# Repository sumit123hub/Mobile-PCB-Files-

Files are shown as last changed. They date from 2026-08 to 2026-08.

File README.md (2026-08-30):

# Custom ESP32 Mobile System PCB

I always dreamed of building my own mobile system. This repo documents my custom ESP32 PCB design featuring a GSM module, display interface, and a complete Battery Management System (BMS).

All subsystems were designed in KiCad and independently validated. Schematics, layout, and testing are complete—I'm just sourcing a suitable display for final integration.

---

## 📷 PCB Images

| Front | Back | 
| :---: | :---: |
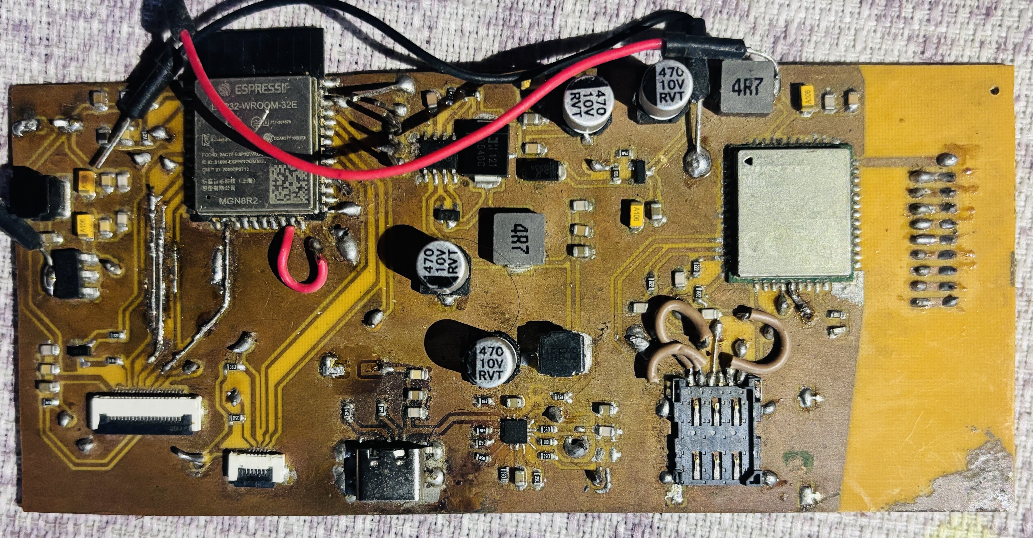
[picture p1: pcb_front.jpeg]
Front
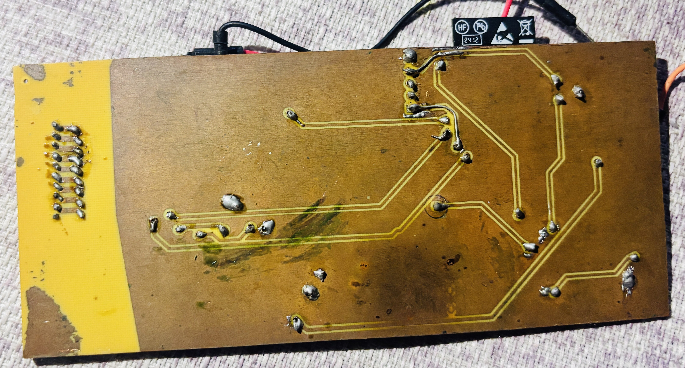
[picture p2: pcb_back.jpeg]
Back
|  |  | 

---

| KiCad View |
| :---: |
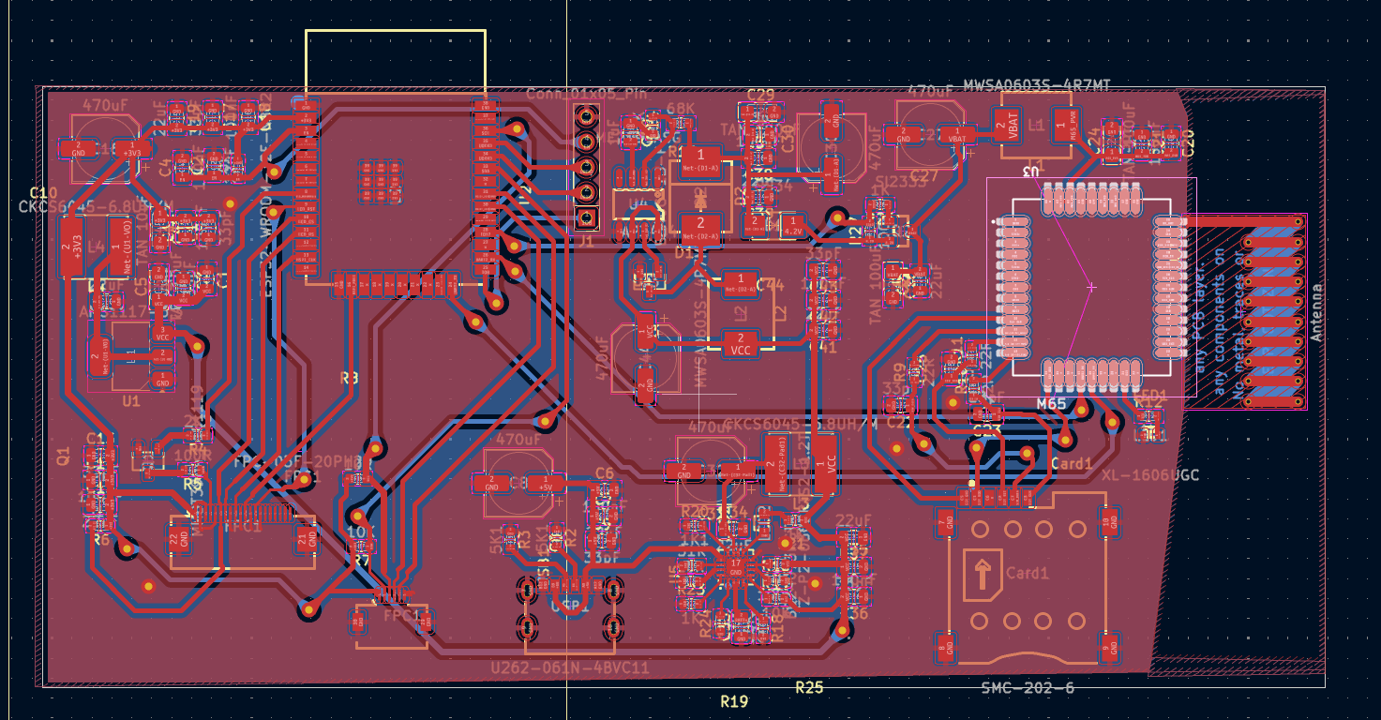
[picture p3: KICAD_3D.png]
3D View
|  |

---

## ✨ What's on the Board

| Component | Description |
| :--- | :--- |
| **ESP32-WROOM** | Main microcontroller (WiFi + BLE) |
| **GSM Module** | Quectel M65 module |
| **Charging Circuit** | BQ Chip |
| **Display Interface** | SPI for display and I2C for charhing |

---

## 📂 Files

- `Mobile_System.kicad_sch` – Schematic
- `Mobile_System.kicad_pcb` – PCB layout
- `gerbers/` – Manufacturing files
- `BOM.csv` – Bill of Materials

---

## 📌 Status

- ✅ Schematic – Complete
- ✅ PCB Layout – Complete
- ✅ BMS Validation – Passed
- ✅ GSM Validation – Passed
- ⏳ Display Integration – In progress (sourcing)
- ⏳ Firmware – Next step

---

## 🛠️ Tools

- **KiCad** – PCB design
- **Arduino / PlatformIO** – Firmware (coming soon)

---

## 👤 Author

**Sumit Sigdel**  
GitHub: [sumit123hub](https://github.com/sumit123hub)

---

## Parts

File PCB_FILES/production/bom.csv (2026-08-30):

Designator | Footprint | Quantity | Value | LCSC Part #
AE1 | Texas_SWRA416_868MHz_915MHz | 1 | Antenna
C1, C11, C13, C17, C21, C22, C23, C25, C31, C35, C43, C9 | 0805 | 12 | 33pF | C696910
C10, C15, C19, C28, C33, C34, C37, C39, C41, C7 | 0805 | 10 | 22uF | C5674
C12, C14, C18, C20, C3, C36, C38, C42, C6 | 0805 | 9 | 100nF | C392963
C16, C27, C30, C32, C44, C8 | CP_Elec_6.3x7.7 | 6 | 470uF | C5189822
C2 | 0805 | 1 | 22uF
C24, C26, C29 | CP_EIA-3216-18_Kemet-A | 3 | TAN 100uF | C27279
C4 | 0805 | 1 | 100nF
C40 | 0805 | 1 | 1uF | C28323
C45, C5 | CP_EIA-3216-18_Kemet-A | 2 | TAN 10uF | C27279
CARD1 | SIM-SMD_SMC-202-6 | 1 | SMC-202-6 | C266634
D1 | DO-214AC_L4.3-W2.7-LS5.0-RD | 1 | SS34 | C2836396
D2 | SMC_L7.1-W6.2-LS8.1-RD | 1 | B540C-13-F | C72264
FPC1 | touch_display_3.5inch | 1 | FPC-05F-20PH20
J1 | PinHeader_1x05_P2.54mm_Vertical | 1 | Conn_01x05_Pin
L1, L2 | IND-SMD_L7.0-W6.6 | 2 | MWSA0603S-4R7MT | C2937097
L3, L4 | IND-SMD_L6.0-W6.0 | 2 | CKCS6045-6.8UH/M | C57254
LED1 | LED-SMD_L1.7-W1.1-R-RD_GREEN | 1 | XL-1606UGC | C965863
LED2 | LED-SMD_L1.6-W1.2-RD | 1 | TZ-P2-0602RTS2-1.2T | C688879
Q1 | SOT-23-3_L2.9-W1.6-P1.90-LS2.8-BR | 1 | MMBT3904_C181119 | C181119
Q2 | SOT-23_L2.9-W1.3-P1.90-LS2.4-BR | 1 | SI2333 | C4748717
Q3 | SOT-23-3_L2.9-W1.3-P1.90-LS2.4-BR-2 | 1 | AP3404 | C2842665
R1 | 0603 | 1 | 10k
R10, R11, R9 | 0603 | 3 | 22R | C3016215
R12 | 0603 | 1 | 1K | C2907179
R13 | 0603 | 1 | 68K | C2907196
R14 | 0603 | 1 | 27K | C22967
R16, R27 | 0603 | 2 | 100K | C25803
R17, R18, R21, R24, R25, R7, R8 | 0603 | 7 | 10K | C3017715
R19, R6 | 0603 | 2 | 51K | C2907180
R2, R3 | 0603 | 2 | 5K1 | C2907114
R20 | 0603 | 1 | 1K1 | C2906975
R22 | 0603 | 1 | 1K | C103309
R23, R26 | 0603 | 2 | 1K | C3017736
R4 | 0603 | 1 | 2K2 | C2907117
R5 | 0603 | 1 | 100R | C125923
U1 | SOT-223-3_TabPin2 | 1 | AMS1117-3.3
U2 | WIFI-SMD_ESP32-WROOM-32E | 1 | ESP32-WROOM-32E-N8R2 | C5361945
U3 | XCVR_M65 | 1 | M65 | Y100443
U4 | SOP-8_L4.9-W3.9-P1.27-LS6.0-BL | 1 | ME2199ASG | C2875120
U5 | QFN-16_L3.0-W3.0-P0.50-TL-EP1.7 | 1 | BQ24073RGTR | C15220
USB1 | USB-SMD_U262-061N-4BVC11 | 1 | U262-061N-4BVC11 | C2764612

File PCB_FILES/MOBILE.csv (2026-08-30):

Id | Designator | Footprint | Quantity | Designation | Supplier and ref
1 | R2,R3 | R_0603_1608Metric | 2 | 5K1
2 | C25,C1,C9,C17,C11,C43,C31,C21,C13,C35,C23,C22 | C_0805_2012Metric | 12 | 33pF
3 | Card1 | SIM-SMD_SMC-202-6 | 1 | SMC-202-6
4 | R4 | R_0603_1608Metric | 1 | 2K2
5 | C3,C18,C12,C4,C38,C42,C20,C14,C36,C6 | C_0805_2012Metric | 10 | 100nF
6 | Q2 | SOT-23_L2.9-W1.3-P1.90-LS2.4-BR | 1 | SI2333
7 | U1 | SOT-223-3_TabPin2 | 1 | AMS1117-3.3
8 | C19,C41,C28,C2,C34,C33,C39,C37,C7,C10,C15 | C_0805_2012Metric | 11 | 22uF
9 | L3,L4 | IND-SMD_L6.0-W6.0 | 2 | CKCS6045-6.8UH/M
10 | R1 | R_0603_1608Metric | 1 | 10k
11 | R11,R10,R9 | R_0603_1608Metric | 3 | 22R
12 | R8,R25,R17,R21,R24,R18,R7 | R_0603_1608Metric | 7 | 10K
13 | C27,C8,C16,C32,C44,C30 | CP_Elec_6.3x7.7 | 6 | 470uF
14 | R19,R6 | R_0603_1608Metric | 2 | 51K
15 | Q3 | SOT-23-3_L2.9-W1.3-P1.90-LS2.4-BR-2 | 1 | AP3404
16 | AE1 | Texas_SWRA416_868MHz_915MHz | 1 | Antenna
17 | U3 | XCVR_M65 | 1 | M65
18 | C45,C5 | CP_EIA-3216-18_Kemet-A | 2 | TAN 10uF
19 | R22,R12,R26,R23 | R_0603_1608Metric | 4 | 1K
20 | R5 | R_0603_1608Metric | 1 | 100R
21 | R13 | R_0603_1608Metric | 1 | 68K
22 | J1 | PinHeader_1x05_P2.54mm_Vertical | 1 | Conn_01x05_Pin
23 | R20 | R_0603_1608Metric | 1 | 1K1
24 | LED2 | LED-SMD_L1.6-W1.2-RD | 1 | TZ-P2-0602RTS2-1.2T
25 | L1,L2 | IND-SMD_L7.0-W6.6 | 2 | MWSA0603S-4R7MT
26 | U4 | SOP-8_L4.9-W3.9-P1.27-LS6.0-BL | 1 | ME2199ASG
27 | USB1 | USB-SMD_U262-061N-4BVC11 | 1 | U262-061N-4BVC11
28 | Q1 | SOT-23-3_L2.9-W1.6-P1.90-LS2.8-BR | 1 | MMBT3904_C181119
29 | D2 | SMC_L7.1-W6.2-LS8.1-RD | 1 | B540C-13-F
30 | C40 | C_0805_2012Metric | 1 | 1uF
31 | U5 | QFN-16_L3.0-W3.0-P0.50-TL-EP1.7 | 1 | BQ24073RGTR
32 | C24,C29,C26 | CP_EIA-3216-18_Kemet-A | 3 | TAN 100uF
33 | R14 | R_0603_1608Metric | 1 | 27K
34 | R27,R16 | R_0603_1608Metric | 2 | 100K
35 | LED1 | LED-SMD_L1.7-W1.1-R-RD_GREEN | 1 | XL-1606UGC
36 | FPC1 | touch_display_3.5inch | 1 | FPC-05F-20PH20
37 | D1 | DO-214AC_L4.3-W2.7-LS5.0-RD | 1 | SS34
38 | U2 | WIFI-SMD_ESP32-WROOM-32E | 1 | ESP32-WROOM-32E-N8R2

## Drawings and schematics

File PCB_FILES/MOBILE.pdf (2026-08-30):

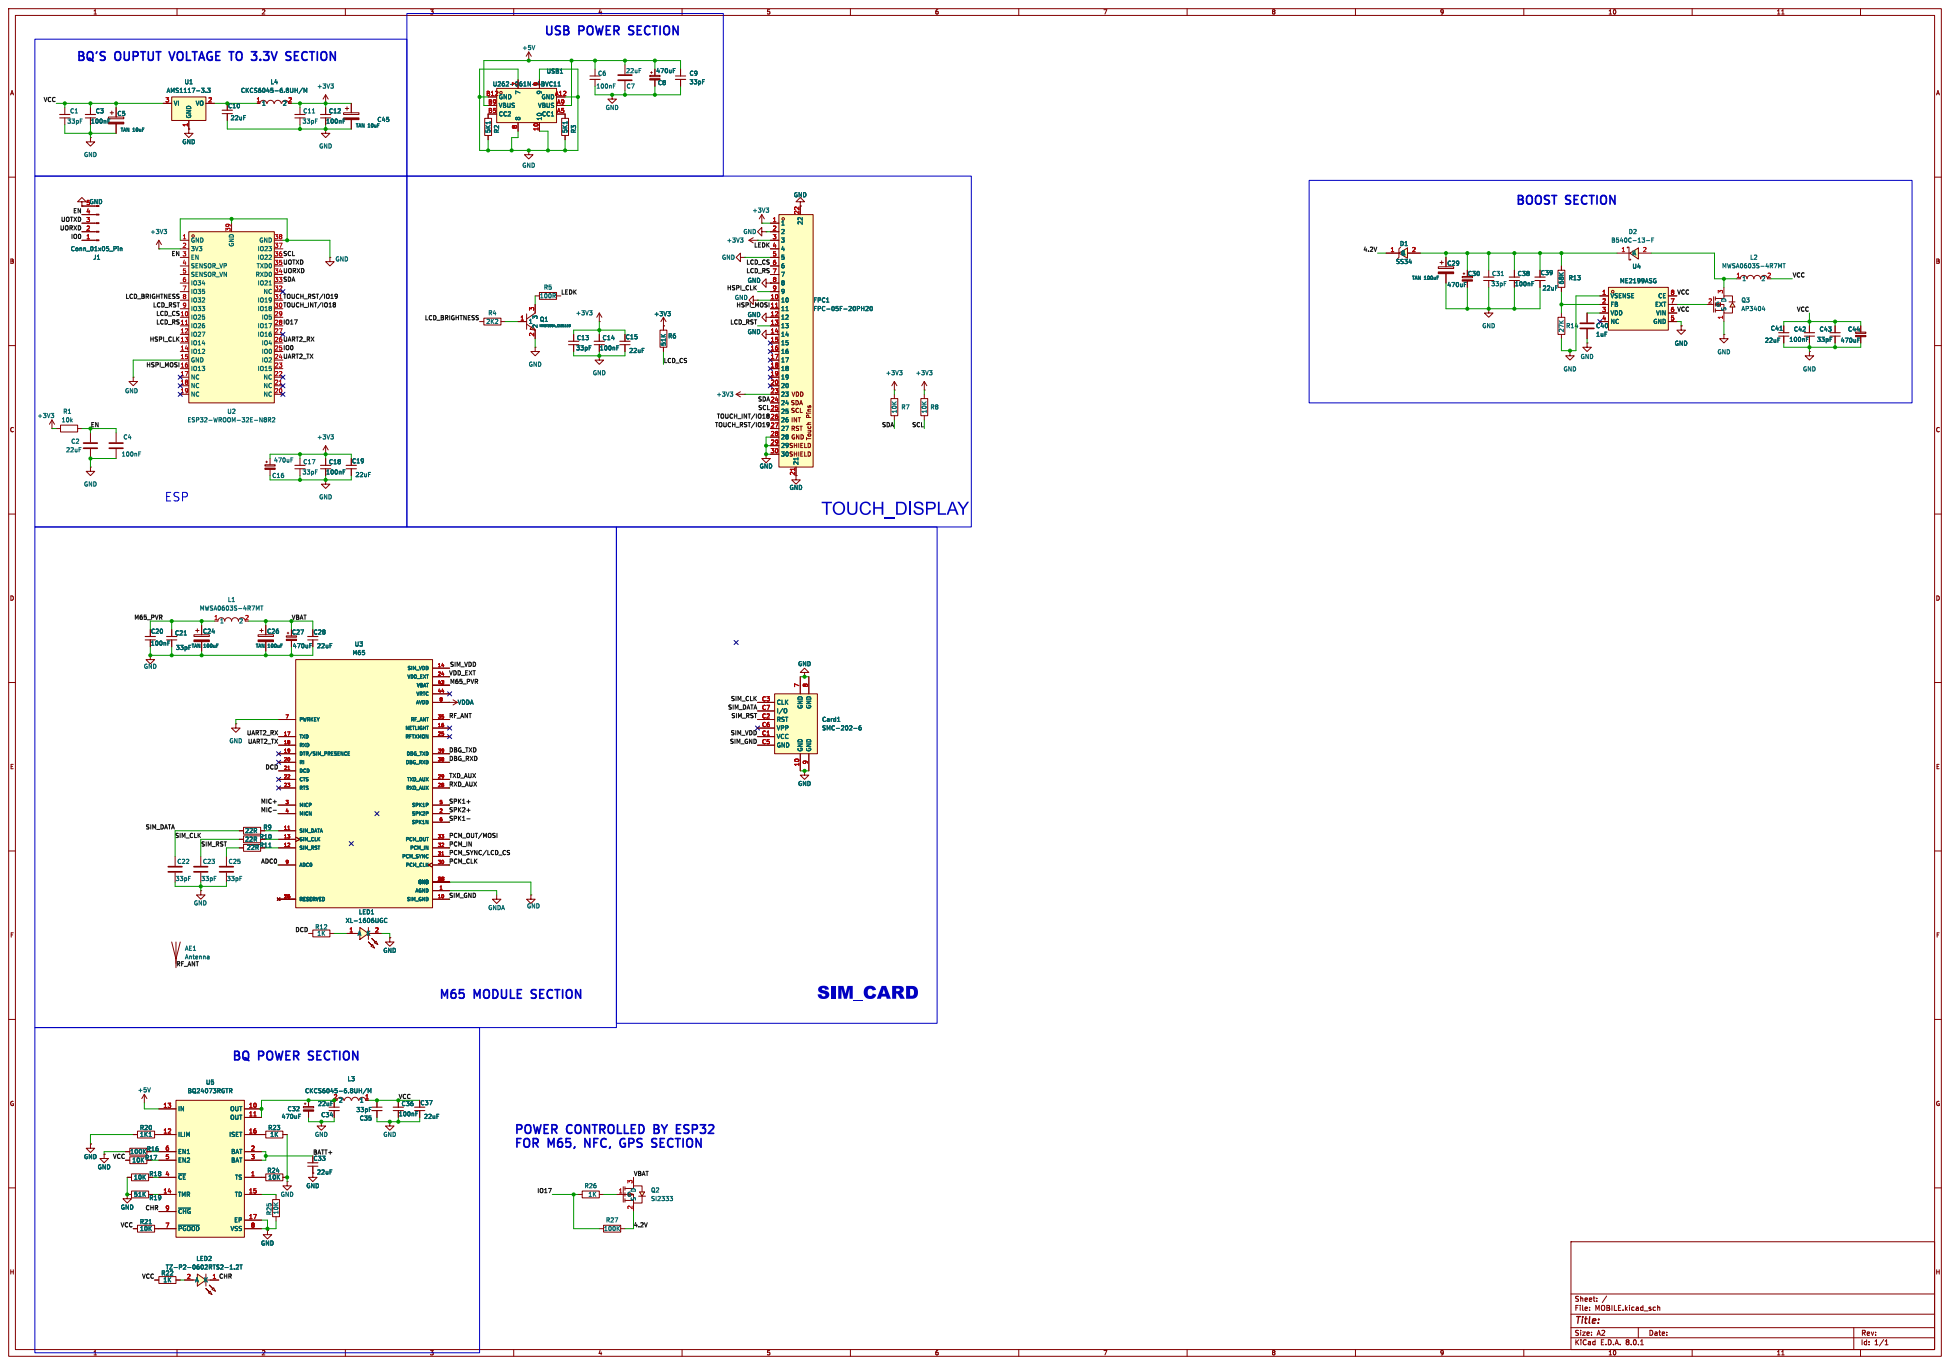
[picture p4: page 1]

BQ'S OUPTUT VOLTAGE TO 3.3V SECTION

9 VCC C1 RST C2 CLK C3 GND C5 VPP C6

POWER CONTROLLED BY ESP32
FOR M65, NFC, GPS SECTION

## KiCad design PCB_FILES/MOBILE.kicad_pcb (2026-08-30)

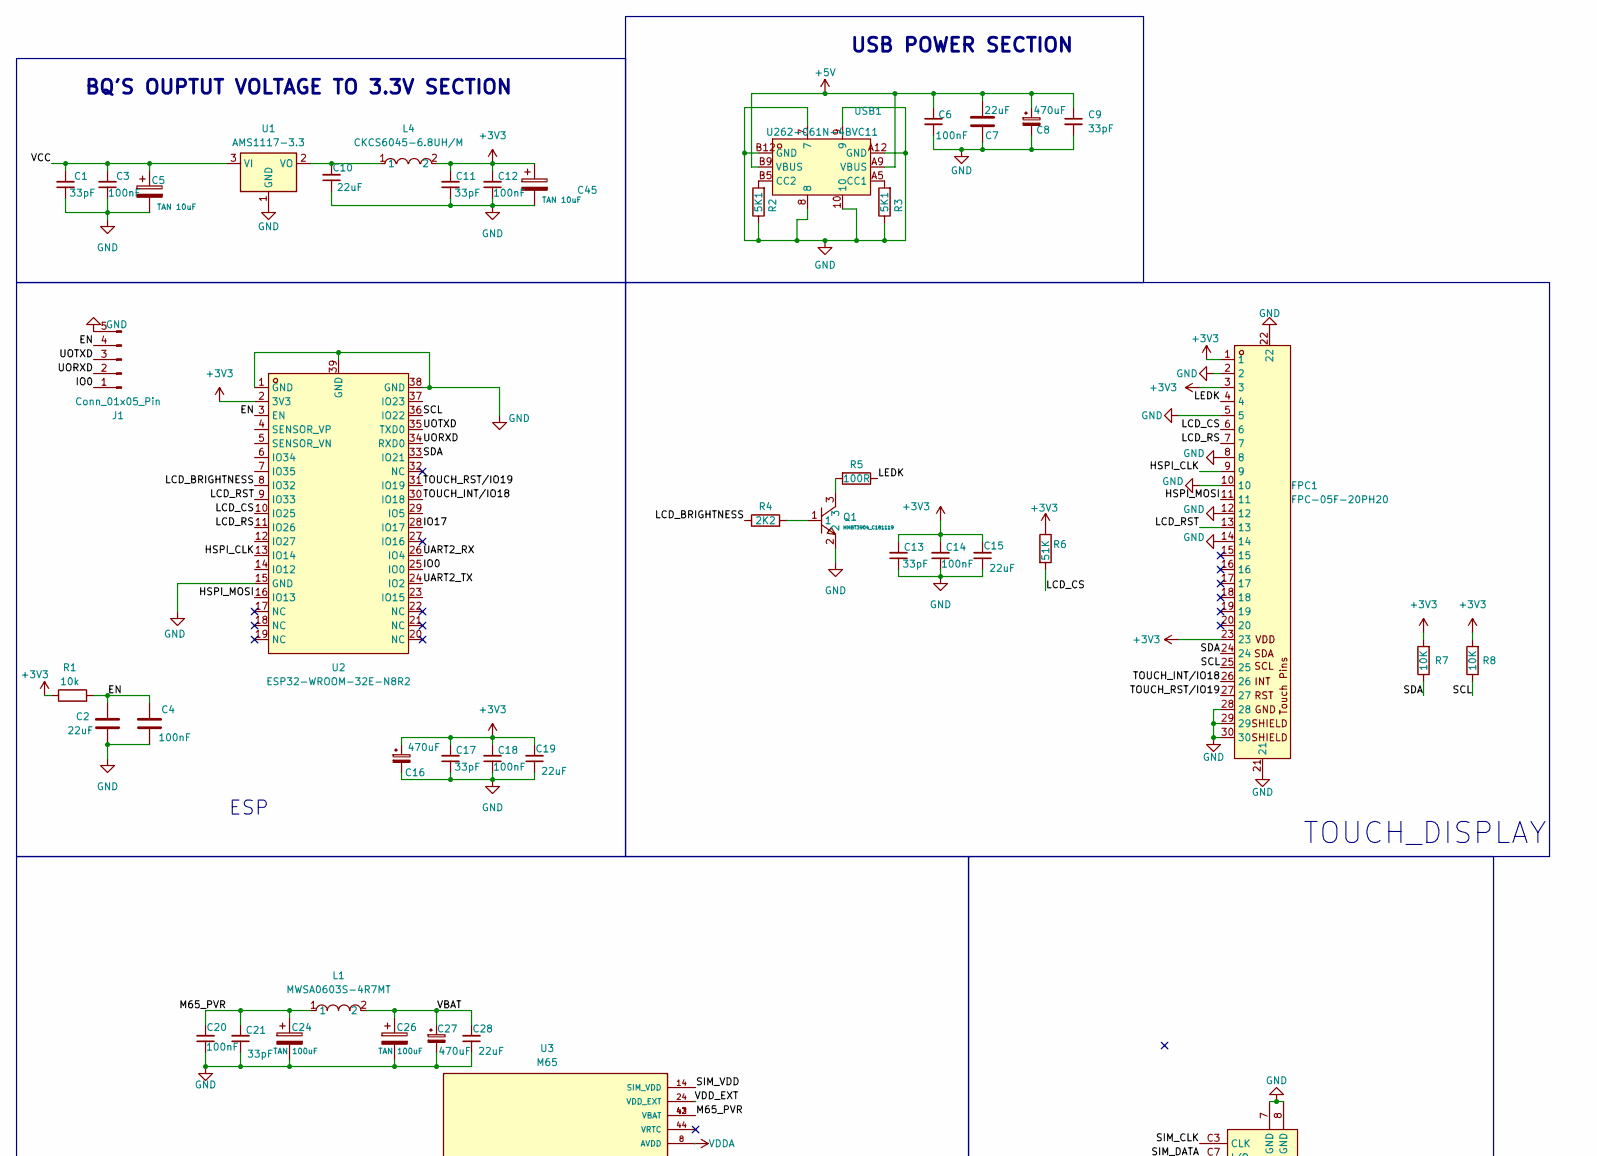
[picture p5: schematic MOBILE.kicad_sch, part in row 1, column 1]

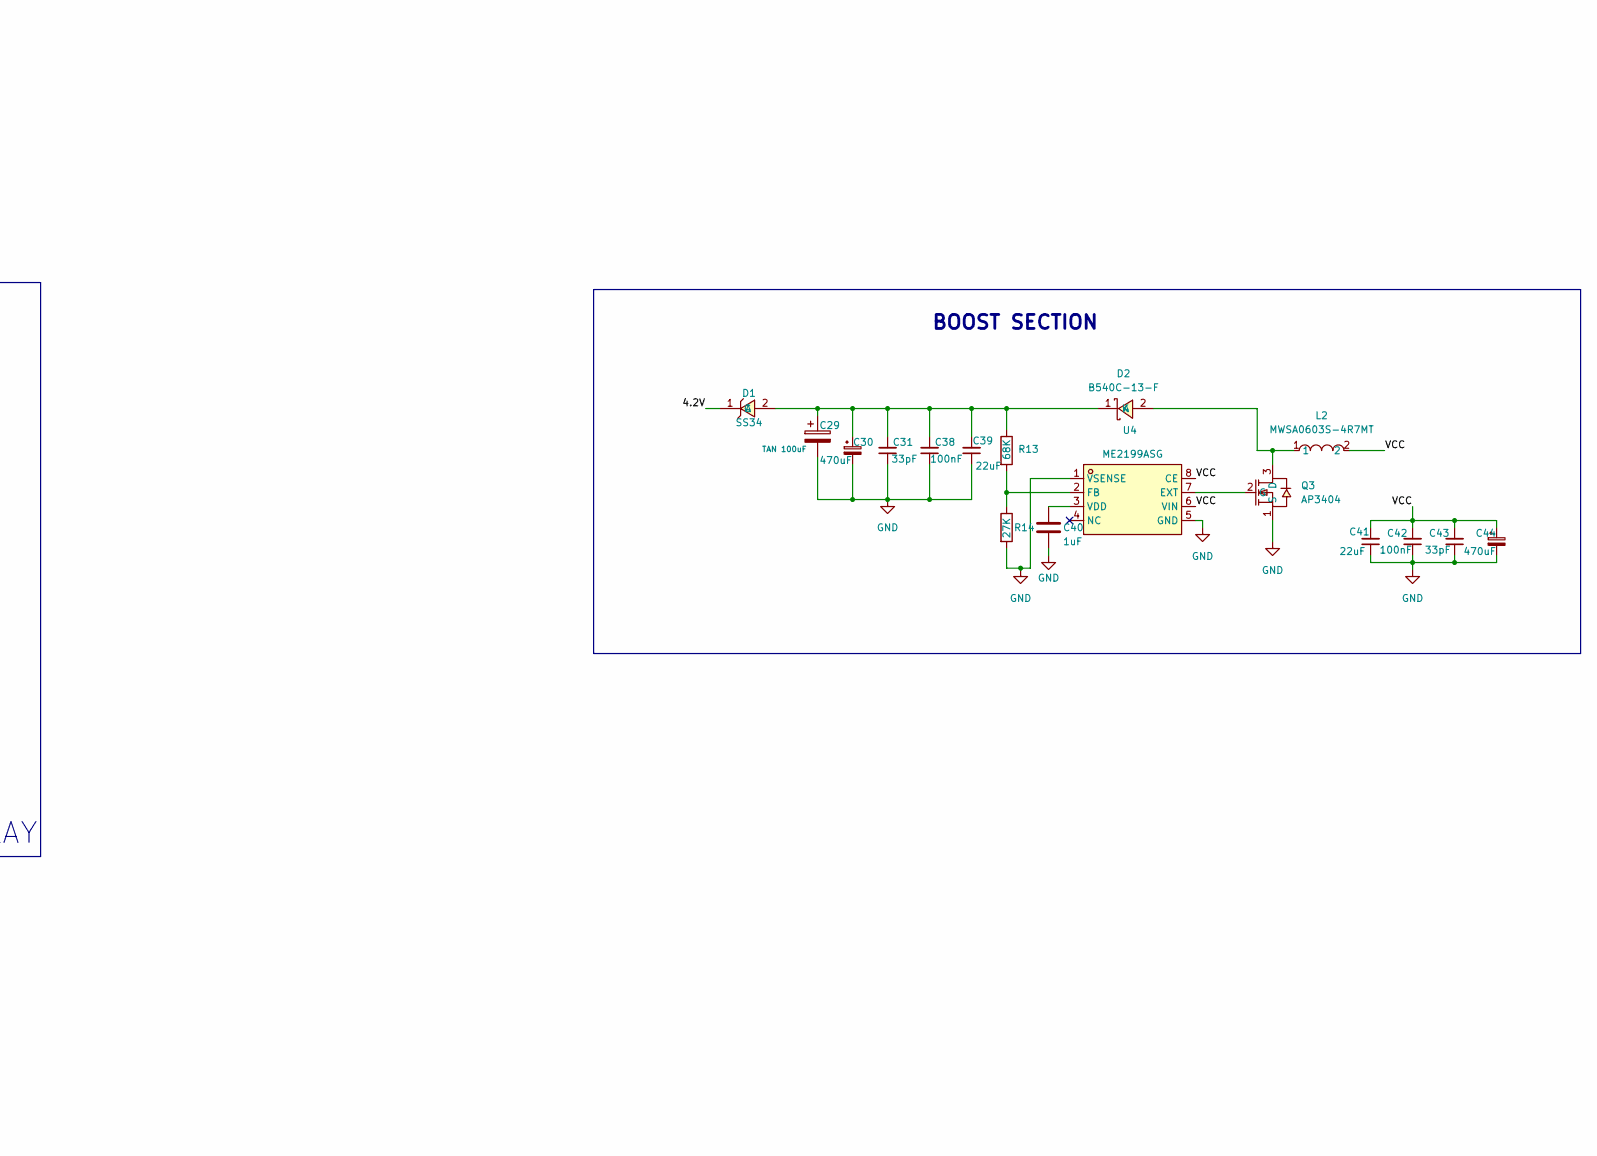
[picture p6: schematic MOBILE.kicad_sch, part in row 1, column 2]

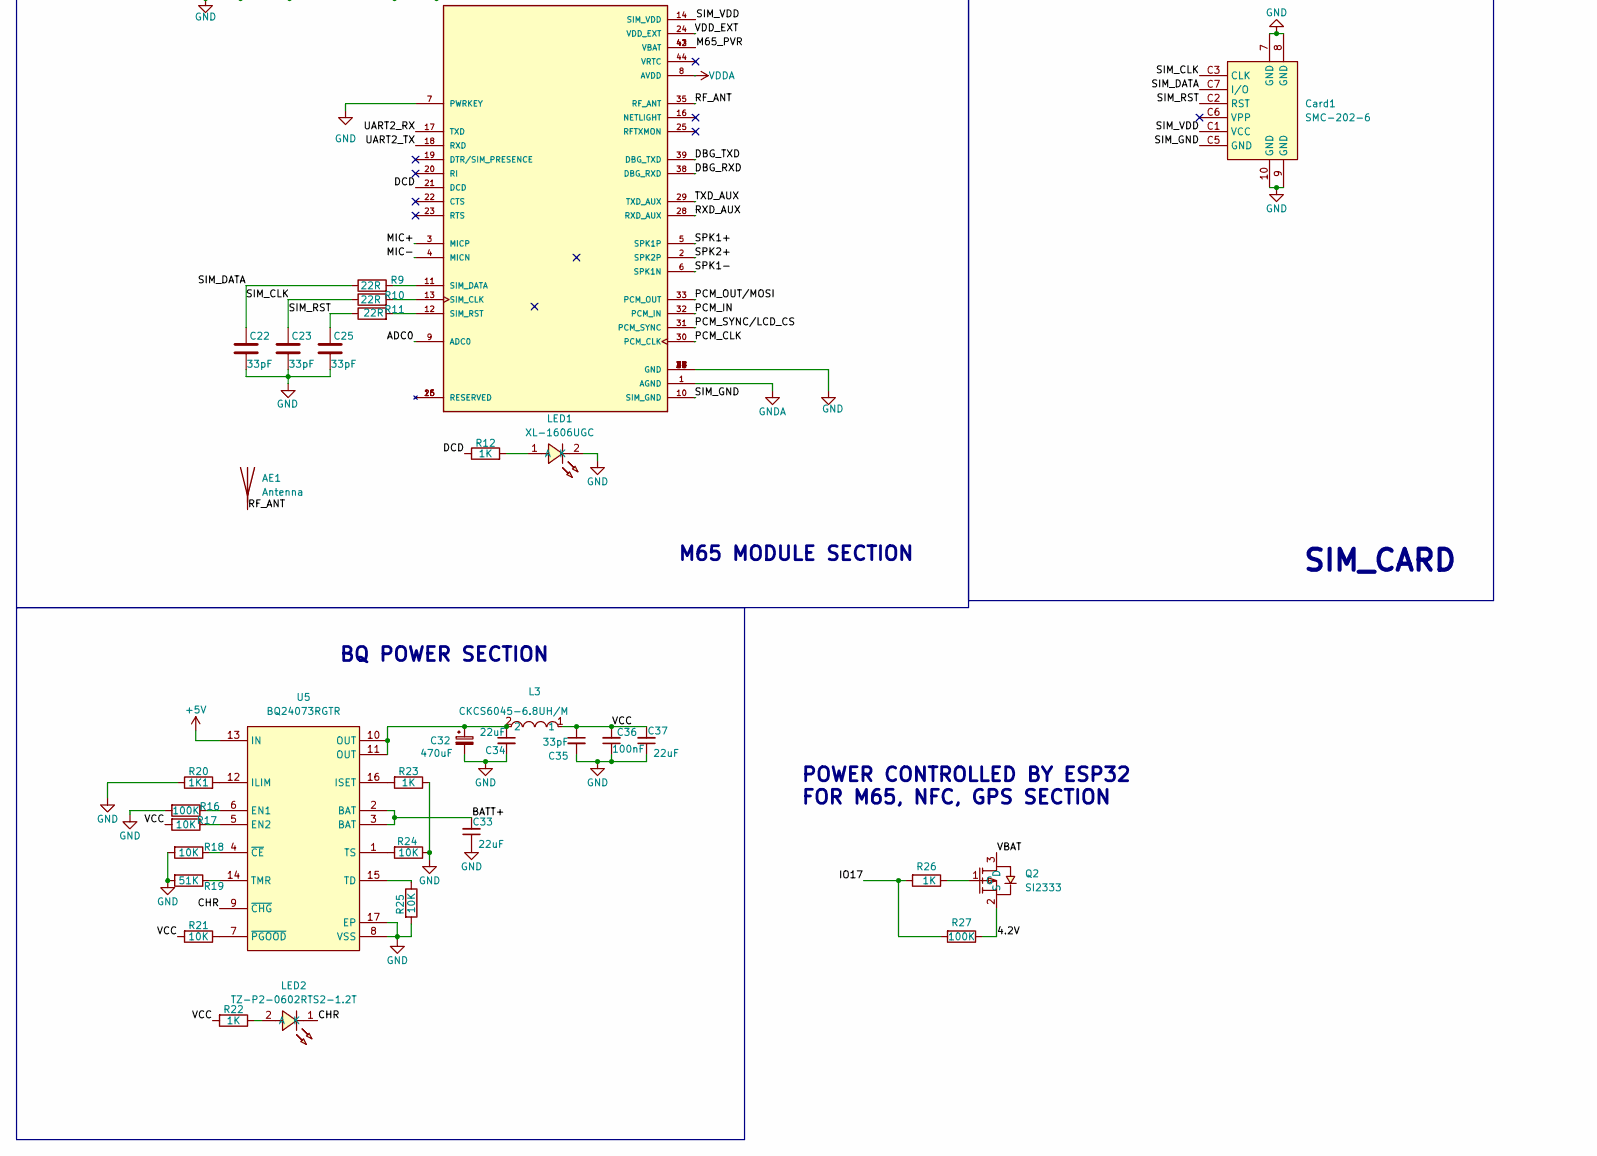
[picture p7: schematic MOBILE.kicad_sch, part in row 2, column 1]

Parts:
AE1: Antenna; Texas_SWRA416_868MHz_915MHz
C1, C11, C13, C17, C21, C31, C35, C43: 33pF; C_0805_2012Metric; LCSC Part # C696910
C2: 22uF; C_0805_2012Metric
C3, C12, C14, C18, C20, C36, C38, C42: 100nF; C_0805_2012Metric; LCSC Part # C392963
C4: 100nF; C_0805_2012Metric
C5, C45: TAN 10uF; CP_EIA-3216-18_Kemet-A; LCSC Part # C27279
C6: 100nF; C_0805_2012Metric; LCSC Part C392963
C7, C10, C15, C19, C28, C33, C34, C37, C39, C41: 22uF; C_0805_2012Metric; LCSC Part # C5674
C8, C16, C27, C30, C32, C44: 470uF; CP_Elec_6.3x7.7; LCSC Part # C5189822
C9, C22, C23, C25: 33pF; C_0805_2012Metric; LCSC Part C696910
C24, C26, C29: TAN 100uF; CP_EIA-3216-18_Kemet-A; LCSC Part # C27279
C40: 1uF; C_0805_2012Metric; LCSC Part C28323
Card1: SMC-202-6; SIM-SMD_SMC-202-6; LCSC Part C266634
D1: SS34; DO-214AC_L4.3-W2.7-LS5.0-RD; LCSC Part # C2836396
D2: B540C-13-F; SMC_L7.1-W6.2-LS8.1-RD; LCSC Part C72264
FPC1: FPC-05F-20PH20; touch_display_3.5inch; LCSC Part C2856803
J1: Conn_01x05_Pin; PinHeader_1x05_P2.54mm_Vertical
L1, L2: MWSA0603S-4R7MT; IND-SMD_L7.0-W6.6; LCSC Part C408447
L3, L4: CKCS6045-6.8UH/M; IND-SMD_L6.0-W6.0; LCSC Part C57254
LED1: XL-1606UGC; LED-SMD_L1.7-W1.1-R-RD_GREEN; LCSC Part C965863
LED2: TZ-P2-0602RTS2-1.2T; LED-SMD_L1.6-W1.2-RD; LCSC Part C688879
Q1: MMBT3904_C181119; SOT-23-3_L2.9-W1.6-P1.90-LS2.8-BR; LCSC Part C181119
Q2: SI2333; SOT-23_L2.9-W1.3-P1.90-LS2.4-BR; LCSC Part C4748717
Q3: AP3404; SOT-23-3_L2.9-W1.3-P1.90-LS2.4-BR-2; LCSC Part C2842665
R1: 10k; R_0603_1608Metric
R2, R3: 5K1; R_0603_1608Metric; LCSC Part # C2907114
R4: 2K2; R_0603_1608Metric; LCSC Part C2907117
R5: 100R; R_0603_1608Metric; LCSC Part C125923
R6: 51K; R_0603_1608Metric; LCSC Part C2907180
R7, R8, R17, R18, R21, R24, R25: 10K; R_0603_1608Metric; LCSC Part # C3017715
R9, R10, R11: 22R; R_0603_1608Metric; LCSC Part C3016215
R12: 1K; R_0603_1608Metric; LCSC Part # C2907179
R13: 68K; R_0603_1608Metric; LCSC Part C2907196
R14: 27K; R_0603_1608Metric; LCSC Part C22967
R16, R27: 100K; R_0603_1608Metric; LCSC Part # C25803
R19: 51K; R_0603_1608Metric; LCSC Part # C2907180
R20: 1K1; R_0603_1608Metric; LCSC Part # C2906975
R22: 1K; R_0603_1608Metric; LCSC Part # C103309
R23, R26: 1K; R_0603_1608Metric; LCSC Part # C3017736
U1: AMS1117-3.3; SOT-223-3_TabPin2
U2: ESP32-WROOM-32E-N8R2; WIFI-SMD_ESP32-WROOM-32E; LCSC Part C5361945
U3: M65; XCVR_M65; PARTREV 1.0; LCSC Part Y100443
U4: ME2199ASG; SOP-8_L4.9-W3.9-P1.27-LS6.0-BL; LCSC Part # C2875120
U5: BQ24073RGTR; QFN-16_L3.0-W3.0-P0.50-TL-EP1.7; LCSC Part C15220
USB1: U262-061N-4BVC11; USB-SMD_U262-061N-4BVC11; LCSC Part C2764612

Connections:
+3V3: C11.2, C12.2, C13.2, C14.2, C15.2, C16.1, C17.2, C18.2, C19.2, C45.1, FPC1.1, FPC1.3, FPC1.23, L4.2, R1.1, R6.1, R7.2, R8.2, U2.2 (3V3)
+5V: C6.1, C7.1, C8.1, C9.1, U5.13 (IN), USB1.A9 (VBUS), USB1.B9 (VBUS)
/4.2V: D1.1 (C), Q2.2 (S), R27.1
/ADC0: U3.9 (ADC0)
/BATT+: C33.2, U5.2 (BAT), U5.3 (BAT)
/CHR: LED2.1 (K), U5.9 (~CHG)
/DBG_RXD: U3.38 (DBG_RXD)
/DBG_TXD: U3.39 (DBG_TXD)
/DCD: R12.1, U3.21 (DCD)
/EN: C2.1, C4.1, J1.4, R1.2, U2.3 (EN)
/HSPI_CLK: FPC1.9, U2.13 (IO14)
/HSPI_MOSI: FPC1.11, U2.16 (IO13)
/IO0: J1.1, U2.25 (IO0)
/IO17: R26.2, R27.2, U2.28 (IO17)
/LCD_BRIGHTNESS: R4.1, U2.8 (IO32)
/LCD_CS: FPC1.6, R6.2, U2.10 (IO25)
/LCD_RS: FPC1.7, U2.11 (IO26)
/LCD_RST: FPC1.13, U2.9 (IO33)
/LEDK: FPC1.4, R5.1
/M65_PVR: C20.2, C21.2, C24.1, L1.1, U3.42 (VBAT), U3.43 (VBAT)
/MIC+: U3.3 (MICP)
/MIC-: U3.4 (MICN)
/PCM_CLK: U3.30 (PCM_CLK)
/PCM_IN: U3.32 (PCM_IN)
/PCM_OUT/MOSI: U3.33 (PCM_OUT)
/PCM_SYNC/LCD_CS: U3.31 (PCM_SYNC)
/RF_ANT: AE1.1 (A), U3.35 (RF_ANT)
/RXD_AUX: U3.28 (RXD_AUX)
/SCL: FPC1.25, R8.1, U2.36 (IO22)
/SDA: FPC1.24, R7.1, U2.33 (IO21)
/SIM_CLK: C23.1, Card1.C3 (CLK), R10.1
/SIM_DATA: C22.1, Card1.C7 (I/O), R9.1
/SIM_GND: Card1.C5 (GND), U3.10 (SIM_GND)
/SIM_RST: C25.1, Card1.C2 (RST), R11.1
/SIM_VDD: Card1.C1 (VCC), U3.14 (SIM_VDD)
/SPK1+: U3.5 (SPK1P)
/SPK1-: U3.6 (SPK1N)
/SPK2+: U3.2 (SPK2P)
/TOUCH_INT/IO18: FPC1.26, U2.30 (IO18)
/TOUCH_RST/IO19: FPC1.27, U2.31 (IO19)
/TXD_AUX: U3.29 (TXD_AUX)
/UART2_RX: U2.26 (IO4), U3.17 (TXD)
/UART2_TX: U2.24 (IO2), U3.18 (RXD)
/UORXD: J1.2, U2.34 (RXD0)
/UOTXD: J1.3, U2.35 (TXD0)
/VBAT: C26.1, C27.1, C28.2, L1.2, Q2.3 (D)
/VCC: C1.2, C3.2, C5.1, C35.1, C36.2, C37.2, C41.2, C42.2, C43.2, C44.1, L2.2, L3.1, R17.2, R21.2, R22.2, U1.3 (VI), U4.6 (VIN), U4.8 (CE)
/VDD_EXT: U3.24 (VDD_EXT)
GND: C1.1, C2.2, C3.1, C4.2, C5.2, C6.2, C7.2, C8.2, C9.2, C10.1, C11.1, C12.1, C13.1, C14.1, C15.1, C16.2, C17.1, C18.1, C19.1, C20.1, C21.1, C22.2, C23.2, C24.2, C25.2, C26.2, C27.2, C28.1, C29.2, C30.2, C31.1, C32.2, C33.1, C34.2, C35.2, C36.1, C37.1, C38.1, C39.1, C40.1, C41.1, C42.1, C43.1, C44.2, C45.2, Card1.7 (GND), Card1.8 (GND), Card1.9 (GND), Card1.10 (GND), FPC1.2, FPC1.5, FPC1.8, FPC1.10, FPC1.12, FPC1.14, FPC1.21, FPC1.22, FPC1.28, FPC1.29, FPC1.30, J1.5, LED1.2 (K), Q1.2, Q3.1 (S), R2.1, R3.1, R14.2, R16.2, R18.2, R19.2, R20.1, R23.1, R24.1, R25.2, U1.1 (GND), U2.1 (GND), U2.15 (GND), U2.38 (GND), U2.39 (GND), U3.7 (PWRKEY), U3.27 (GND), U3.34 (GND), U3.36 (GND), U3.37 (GND), U3.40 (GND), U3.41 (GND), U4.1 (VSENSE), U4.5 (GND), U5.8 (VSS), U5.17 (EP), USB1.7, USB1.8, USB1.9, USB1.10, USB1.A12 (GND), USB1.B12 (GND)
GNDA: U3.1 (AGND)
unnamed: C32.1, C34.1, L3.2, U5.10 (OUT), U5.11 (OUT)
unnamed: C29.1, C30.1, C31.2, C38.2, C39.2, D1.2 (A), D2.1 (K), R13.1
unnamed: D2.2 (A), L2.1, Q3.3 (D)
unnamed: LED1.1 (A), R12.2
unnamed: LED2.2 (A), R22.1
unnamed: Q1.1, R4.2
unnamed: Q1.3, R5.2
unnamed: Q2.1 (G), R26.1
unnamed: Q3.2 (G), U4.7 (EXT)
unnamed: C10.2, L4.1, U1.2 (VO)
unnamed: R10.2, U3.13 (SIM_CLK)
unnamed: R9.2, U3.11 (SIM_DATA)
unnamed: R11.2, U3.12 (SIM_RST)
unnamed: R13.2, R14.1, U4.2 (FB)
unnamed: C40.2, U4.3 (VDD)
unnamed: R16.1, U5.6 (EN1)
unnamed: R17.1, U5.5 (EN2)
unnamed: R20.2, U5.12 (ILIM)
unnamed: R23.2, U5.16 (ISET)
unnamed: R25.1, U5.15 (TD)
unnamed: R19.1, U5.14 (TMR)
unnamed: R24.2, U5.1 (TS)
unnamed: R18.1, U5.4 (~CE)
unnamed: R21.1, U5.7 (~PGOOD)
unnamed: R3.2, USB1.A5 (CC1)
unnamed: R2.2, USB1.B5 (CC2)
VDDA: U3.8 (AVDD)

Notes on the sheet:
USB POWER SECTION
POWER CONTROLLED BY ESP32 FOR M65, NFC, GPS SECTION
TOUCH_DISPLAY
ESP
SIM_CARD
M65 MODULE SECTION
BOOST SECTION
BQ'S OUPTUT VOLTAGE TO 3.3V SECTION
BQ POWER SECTION

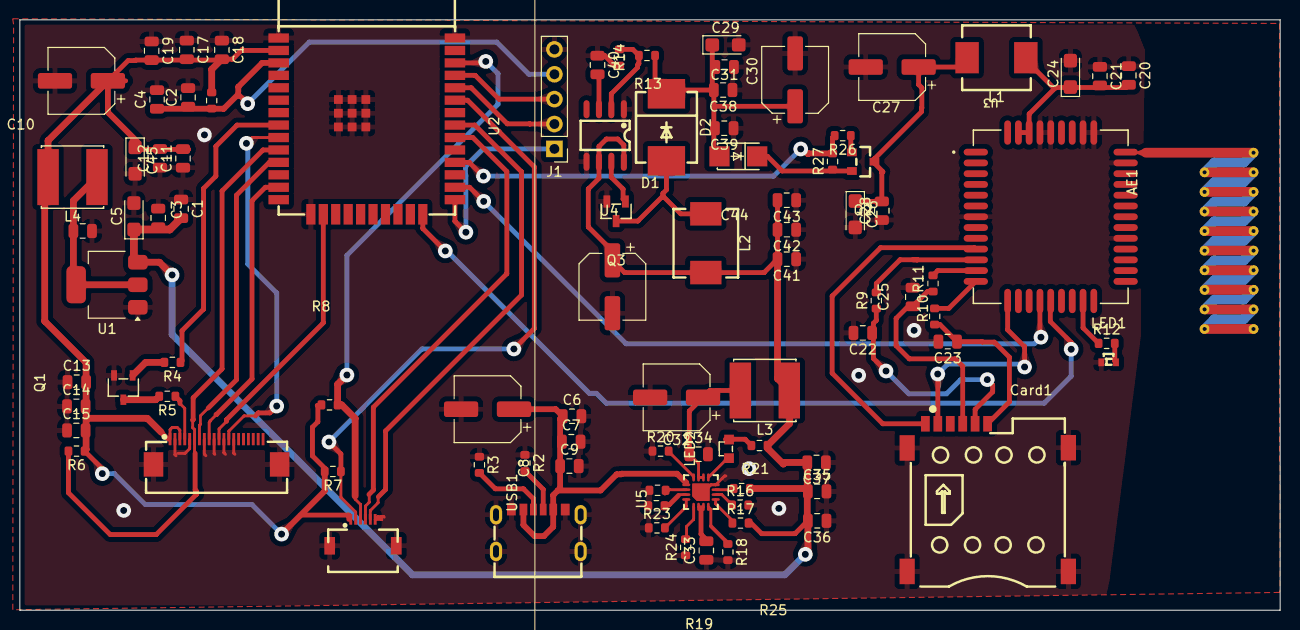
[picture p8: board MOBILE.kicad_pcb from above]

Board: 2 copper layers, 128.7 x 60.3 mm, 92 parts (0 on the bottom side), 60 nets.

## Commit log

2026-08-30 PCB files commit
    [MOBILE.kicad_pcb, MOBILE.kicad_sch]
2026-08-30 Update PCB images layout in README
    Reorganized PCB images section in README to separate KiCad 3D view.
2026-08-30 3rd commit
    [MOBILE-B_Adhesive.gbr, MOBILE-B_Cu.gbr, MOBILE-B_Mask.gbr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]
